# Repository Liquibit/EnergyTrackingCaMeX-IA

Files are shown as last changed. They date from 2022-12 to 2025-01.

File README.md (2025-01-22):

# EnergyTrackingCaMeX-IA
Energy tracking project for CaMéX-IA

This project exists of 4 parts:
- Energy Measurement device
- MODBUS-to-DASH7 device
- DASH7 gateway
- Gateway software to Scorpio

We will go over each part in this overview.

## Energy Measurement device

For this project, we used the Accuenergy AcuRev 1312-RCT-X0 together with 3 Rogowski coils. The official manual can be found [on their official website](https://www.accuenergy.com/wp-content/uploads/AcuRev-1312-User-Manual-Canada-Measurements-Approved.pdf). This device then measures the current over the three different phases and combines them. At the moment, only apparent and real energy are used in the rest of the project.

## MODBUS-to-DASH7 device

Custom hardware made by LiQuiBit. Every 10 minutes, it communicates over RS485 with the energy measurement device and sends this data over DASH7. 

The data gets structured as a file in the following format:

EnergyFile:
|Field|Type|
|---|---|
|apparent energy/phase 1|signed int 64|
|apparent energy/phase 2|signed int 64|
|apparent energy/phase 3|signed int 64|
|active energy/phase 1|signed int 64|
|active energy/phase 2|signed int 64|
|active energy/phase 3|signed int 64|
|Current/phase 1|signed int 32|
|Current/phase 2|signed int 32|
|Current/phase 3|signed int 32|
|Voltage/phase 1|signed int 16|
|Voltage/phase 2|signed int 16|
|Voltage/phase 3|signed int 16|
|Received Signal Strength|signed int 16|
|valid measurement|boolean|

Valid measurement indicates if it succeeded at reading out the values from the measurement device. 

You can find the firmware for this device in the DASH7-firmwares folder. 

For instructions on how to build or modify the application, you can take a look at [the LiQuiBit documentation](https://docs.liquibit.be/docs/Sub-iot/).

## DASH7 gateway

Using the [IOWAY gateway](https://www.liquibit.be/our_product.html) from LiQuiBit. Using the jumpers, the module is configured to forward DASH7 messages directly over UART instead of sending it to the ESP32. 

The firmware on the IOWAY gateway is the default IOWAY gateway application of the Sub-IoT stack. More information can be found in [the LiQuiBit documentation](https://docs.liquibit.be/docs/The-IOWAY-firmware/).

## Gateway software to Scorp-IO

For this project, this software was deployed on a raspberry pi. All necessary parts can be found in the Gateway-software folder.

The software is written in python3 as it's fully dependant on [the PyD7A library](https://github.com/liquibit/pyd7a). It is configured to receive messages from the serial connection, parse them into known files and forward it over MQTT to Scorp-IO. This sends all configuration to Scorp-IO on the first message of a device and does not require any extra configuration up front.

## Setting up the OS

First pull the code from the public github and put all aspects in the appropriate locations.
```
sudo git clone https://github.com/Liquibit/EnergyTrackingCaMeX-IA.git --recurse-submodules /opt/EnergyTrackingCaMeX-IA
sudo chmod +x /opt/EnergyTrackingCaMeX-IA/Gateway-software/os-config/gateway
sudo ln -s /opt/EnergyTrackingCaMeX-IA/Gateway-software/os-config/gateway /bin/gateway
sudo ln -s /opt/EnergyTrackingCaMeX-IA/Gateway-software/os-config/gateway.monit /etc/monit/conf.d/
sudo chown root:root /opt/EnergyTrackingCaMeX-IA/Gateway-software/os-config/PIOWAY
sudo ln -s /opt/EnergyTrackingCaMeX-IA/Gateway-software/os-config/PIOWAY /etc/logrotate.d/
```

This will set up the following things:
- Monit will make sure the code keeps running, restarts it when something goes wrong and starts it up on boot.
- Logrotate will rotate and compress the logs every week to make sure we're not using too much memory.

Then, make sure your python3 instance has all requirements installed
```
sudo python3 -m pip install -r /opt/EnergyTrackingCaMeX-IA/Gateway-software/pyd7a/requirements.txt
```

Now, you should be good to go after a reboot!

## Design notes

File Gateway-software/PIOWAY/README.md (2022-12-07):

# Gateway software for connection between DASH7 gateway and Siemens Mindsphere IoT Platform
This application sets up a connection with home assistant using MQTTS. The device should be configured up front using the UI or by posting to topics of the MQTT broker.

This application is meant to run on a raspberry Pi with a LiQuiBit IOWay gateway plugged into the USB port.

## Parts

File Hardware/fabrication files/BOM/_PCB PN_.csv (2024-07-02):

Comment | Description | Designator | Footprint | Quantity
SKSGACE010 | Keypad Switch, 1 Switches, SPST, Momentary-tactile, 0.05A, 12VDC, 1.6N, Solder Terminal, Surface Mount-straight | B1, B2 | RKC2SJF170SMTRLFS-Footprint-1 | 2
74LVC1G14GV | Inverter, LVC/LCX/Z Series, 1-Func, 1-Input, CMOS, PDSO5 | B3 | 74LVC1G14GV,125-Footprint-1 | 1
TDH541S485S | UART_MODBUS_CONVERTER | B4 | TD541S485H-Footprint-1 | 1
3RL090M-5-S | 3R-5-S Series 5 mm 600 V 5 kA Surface Mount Gas Discharge Tube | B5 | 2036-09-SM-RPLF-H-Footprint-1 | 1
CC0603KPX7R8BB105 | Ceramic Capacitor, Multilayer, Ceramic, 25V, 10% +Tol, 10% -Tol, X7R, 15% TC, 1uF, Surface Mount, 0603 | C1, C9, C19, C20 | FP-CC0603-DA-MFG | 4
C0603C103K2RACTU | Ceramic Capacitor, Multilayer, Ceramic, 200V, 10% +Tol, 10% -Tol, X7R, 15% TC, 0.01uF, Surface Mount, 0603 | C2 | FP-C0603C-CF-IPC_B | 1
GRM188Z71E225KE43D | Ceramic Capacitor, Multilayer, Ceramic, 25V, 10% +Tol, 10% -Tol, X7R, 15% TC, 2.2uF, Surface Mount, 0603 | C3 | FP-GRM188-0_2-IPC_C | 1
CC0603KRX7R9BB104 | Ceramic Capacitor, Multilayer, Ceramic, 25V, 10% +Tol, 10% -Tol, X7R, 15% TC, 0.1uF, Surface Mount, 0603 | C4, C8, C11, C13, C14, C16, C17, C18 | FP-0603-L_1_6_0_15-W_0_81-MFG | 8
GRM188R60J106ME47D | Ceramic Capacitor, Multilayer, Ceramic, 6.3V, 20% +Tol, 20% -Tol, X5R, 15% TC, 10uF, Surface Mount, 0603 | C10, C12 | FP-GRM188-0_1-e0_2_0_55-MFG | 2
CC1206KKX7RDBB102 | Ceramic Capacitor, Multilayer, Ceramic, 2000V, 10% +Tol, 10% -Tol, X7R, 15% TC, 0.001uF, Surface Mount, 1206 | C15 | FP-CC1206-0_3-1_45-IPC_A | 1
CC0603KRX7R9BB101 | Ceramic Capacitor, Multilayer, Ceramic, 50V, 10% +Tol, 10% -Tol, X7R, 15% TC, 0.0001uF, Surface Mount, 0603 | C21, C22 | FP-CC0603-DA-IPC_B | 2
APT1608SURCK | Single Color LED, Hyper Red, Water Clear, 1.2mm | D1, D4 | FP-APT1608EC-MFG | 2
SMAJ5.0A | Trans Voltage Suppressor Diode, 400W, 5V V(RWM), Unidirectional, 1 Element, Silicon, DO-214AC | D2 | BOUR-SMA-2_V | 1
APG1608CGKC/T | Single Color LED, Green, Water Clear, 1.2mm | D3 | FP-APG1608CGKC-T-MFG | 1
2920L075DR | PTC Thermistor, 30V, 0.35ohm, Surface Mount | F1 | FP-2920L050DR-MFG | 1
BLM18AG121SN1D | Chip Ferrite Bead, 0603, 120O @ 100MHz, 0.18O, 25%, 800mA | FB1 | FP-BLM18-0_15-t0_8-IPC_B | 1
VI0921550000G | Barrier Strip Terminal Block | j4 | VI0921550000G-Footprint-1 | 1
HJ-SMA402 | RF SMA Connector | J5 | CON-REVSMA-RA | 1
105133-0001 | USB Connector, 5 Contact(s), Female, Right Angle, Surface Mount Terminal, Locking, Receptacle | J6 | MOLX-105133-0001_V | 1
ACM2520-301-2P-T002 | Ferrite Chip, 2 Function(s), 20V, 0.4A, 4 Pin(s) | L1 | FP-ACM2520-2P-MFG | 1
CMWX1ZZABZ-078 | Microcontroller/radio package | MD1 | FP-CMWX1ZZABZ-078-MFG | 1
PZ127VS-12-10-H10-A38 | Male Header, Pitch 1.27 mm, 2 x 5 Position, Height 5.96 mm, -55 to 125 degC, RoHS, Bulk | P1 | SMTC-FTSH-105-01-L-DV_V | 1
RL1210FR-070R5L | Fixed Resistor, Metal Glaze/thick Film, 0.5W, 0.5ohm, 0.5V, 1% +/-Tol, 300ppm/Cel, Surface Mount, 1210 | R1 | RESC3126X65X50NL10T20 | 1
AC0805FR-07100RL | Fixed Resistor, Metal Glaze/thick Film, 0.125W, 100ohm, 150V, 1% +/-Tol, 100ppm/Cel, Surface Mount, 0805 | R2, R3, R4 | FP-AC0805-IPC_A | 3
CRCW04020000Z0ED | Metal Glaze/thick Film, 0.063W, 0ohm, Surface Mount, 0402 | R7, R12, R14 | FP-CRCW0402-e3-IPC_A | 7
RC0402FR-0710KL | Fixed Resistor, Metal Glaze/thick Film, 0.0625W, 10000ohm, 50V, 1% +/-Tol, 100ppm/Cel, Surface Mount, 0402 | R8 | RESC1005X40X25NL05T10 | 1
RT1206FRE071ML | Fixed Resistor, Thin Film, 0.25W, 1000000ohm, 200V, 1% +/-Tol, 50ppm/Cel, Surface Mount, 1206 | R9 | RESC3116X65X40ML10T20 | 1
CRCW12061K00JNEC | Fixed Resistor, Metal Glaze/thick Film, 0.25W, 1000ohm, 200V, 5% +/-Tol, 200ppm/Cel, Surface Mount, 1206 | R10, R18 | FP-CRCW1206-e3-IPC_A | 2
SMW22R7JT | Fixed Resistor, Wire Wound, 2W, 2.7ohm, 300V, 5% +/-Tol, 200ppm/Cel, Surface Mount, 2616 | R11, R15 | SMW22R7JT-Footprint-1 | 2
PTS526SK15SMTR2LFS | TACT 5.2 X 5.2, 1.5 MM H, 260GF, | SW1 | FP-PTS526SK15SMTR2LFS-MFG | 1
SPX3819M5-L-3-3/TR | Fixed Positive LDO Regulator, 3.3V, 0.7V Dropout, PDSO5 | U1 | SOT95P280X145-5N | 1
TPD2S017DBVR | Trans Voltage Suppressor Diode, 5V V(RWM), Unidirectional, 4 Element, Silicon | U2 | DBV0006A_N | 1
SM712.TCT | Trans Voltage Suppressor Diode, 400W, 12V V(RWM), Unidirectional, 4 Element, Silicon | U3 | SMTC-SOT23-3_V | 1

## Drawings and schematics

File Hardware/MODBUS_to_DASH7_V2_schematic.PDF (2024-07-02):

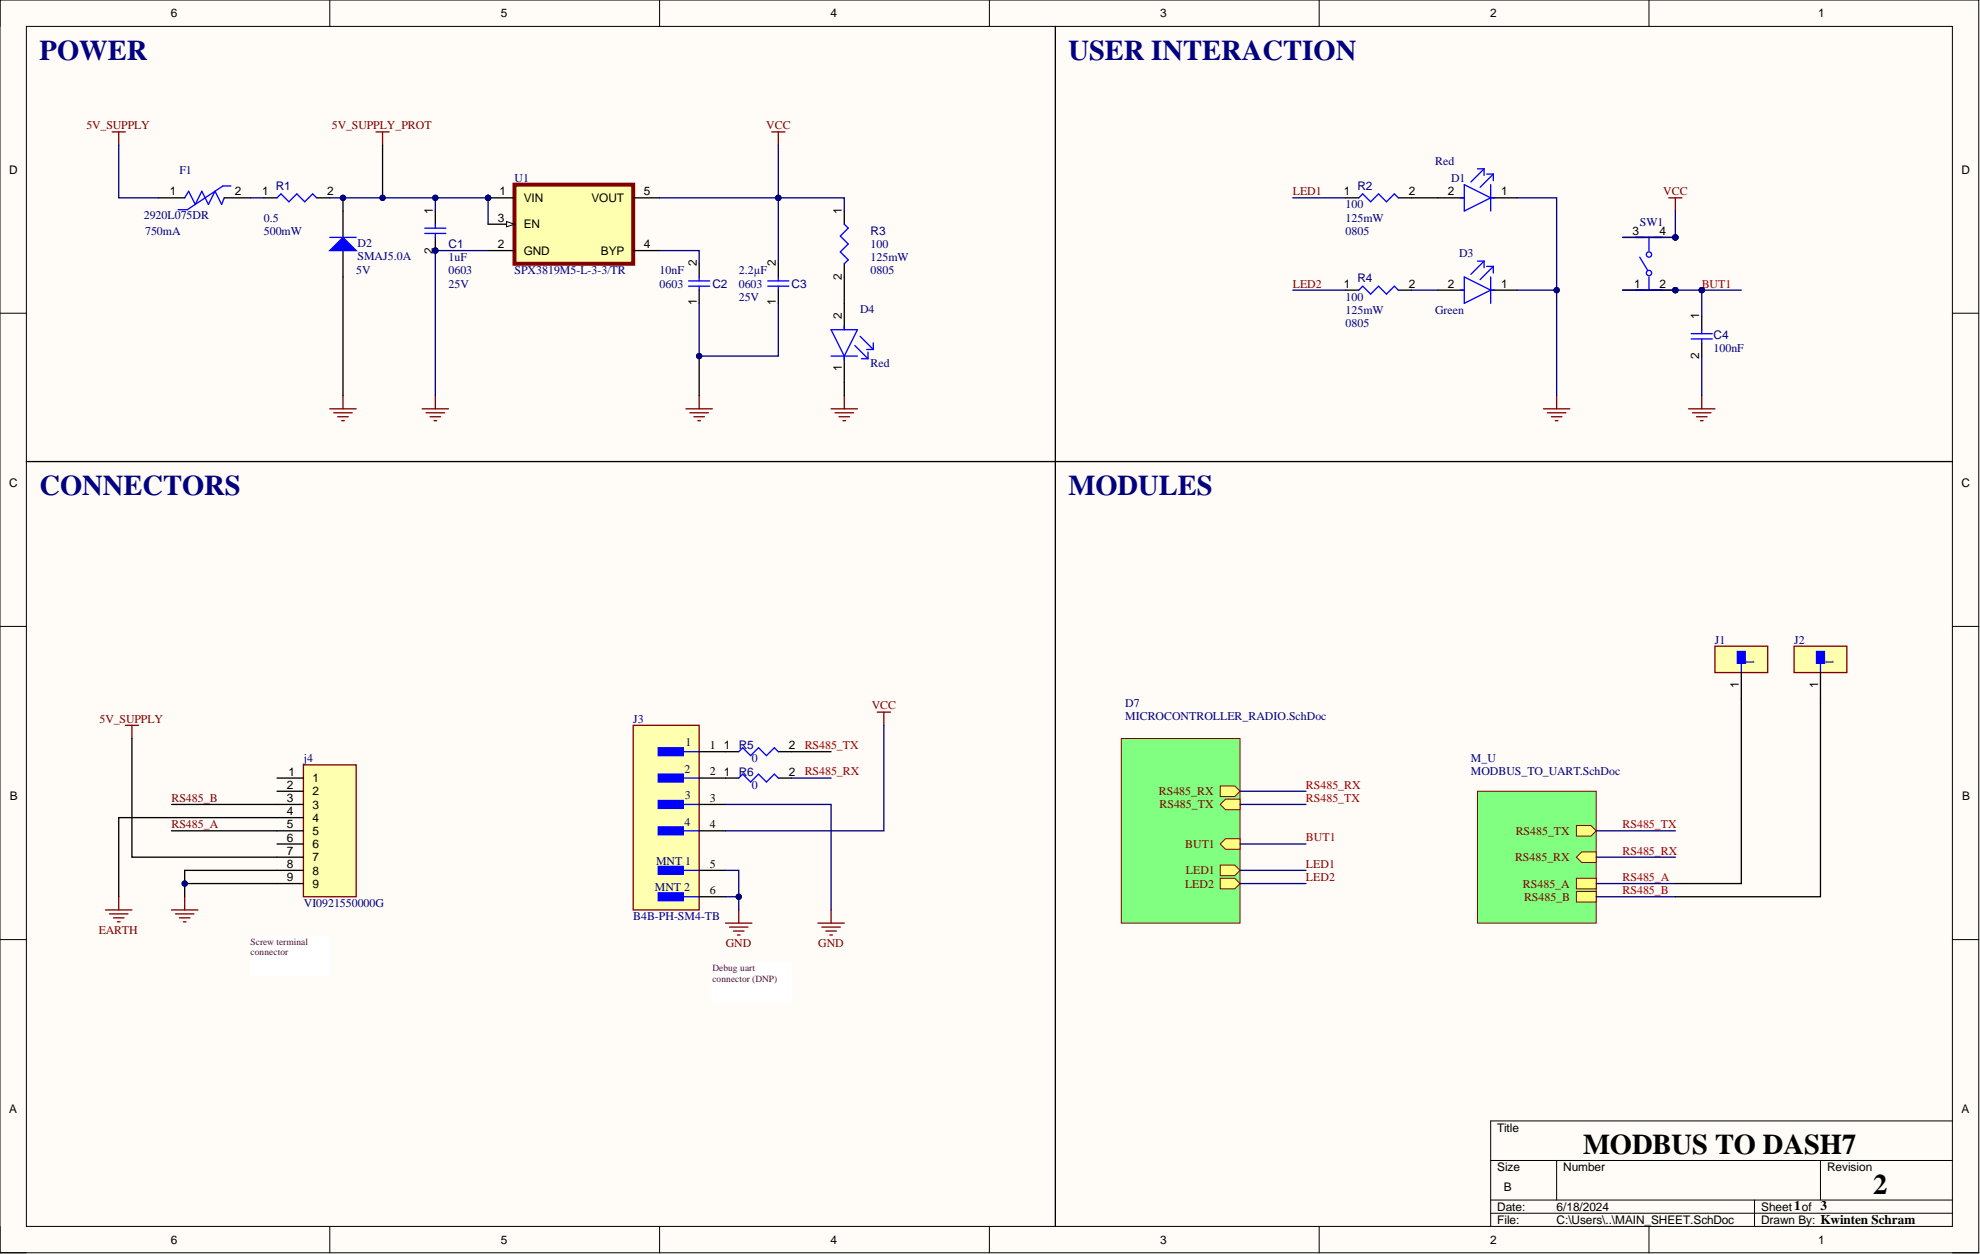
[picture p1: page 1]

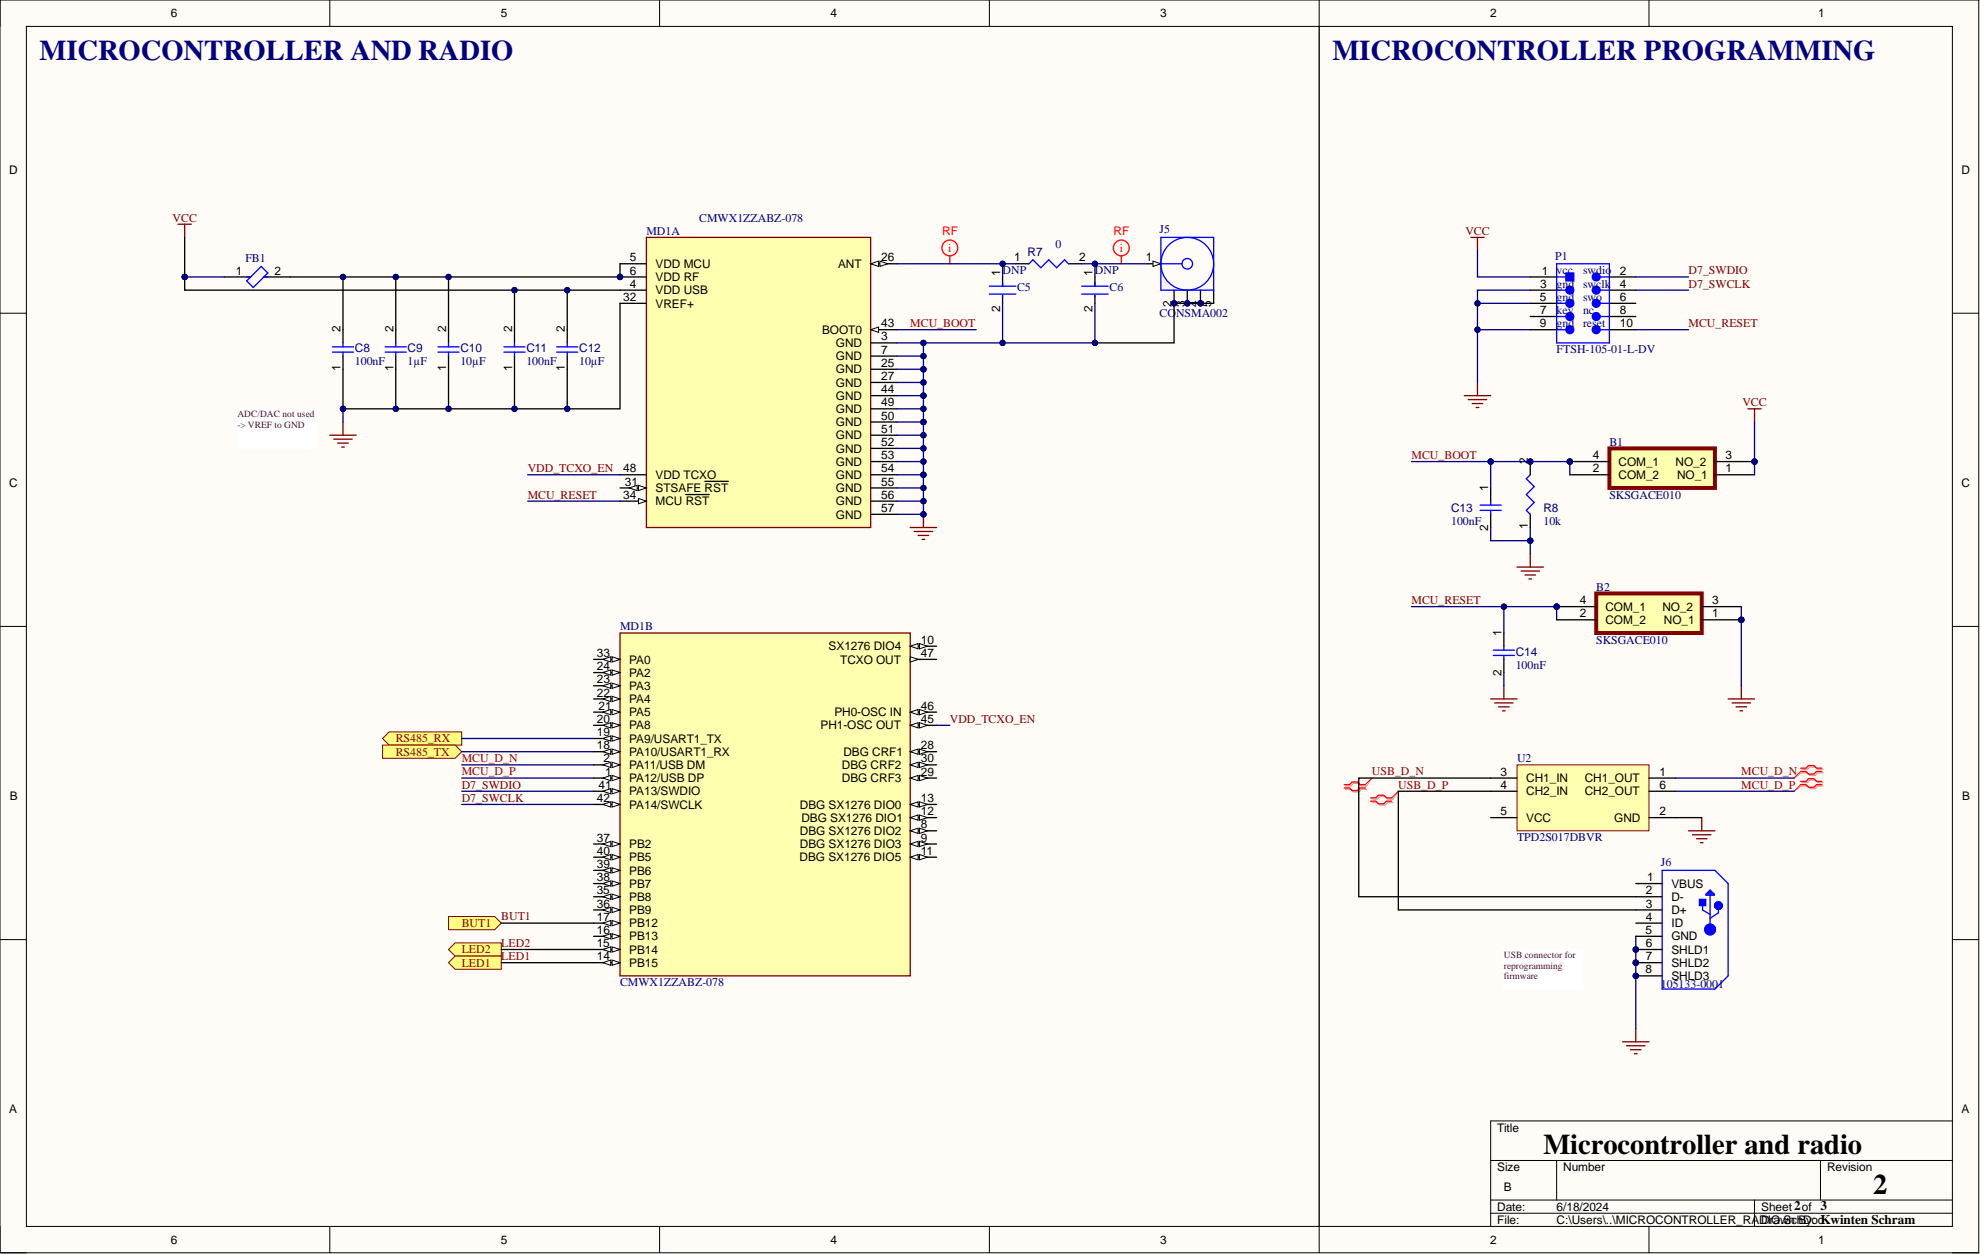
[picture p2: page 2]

ADC/DAC not used
-> VREF to GND

USB_D_P | CH2_IN 4

VCC 5

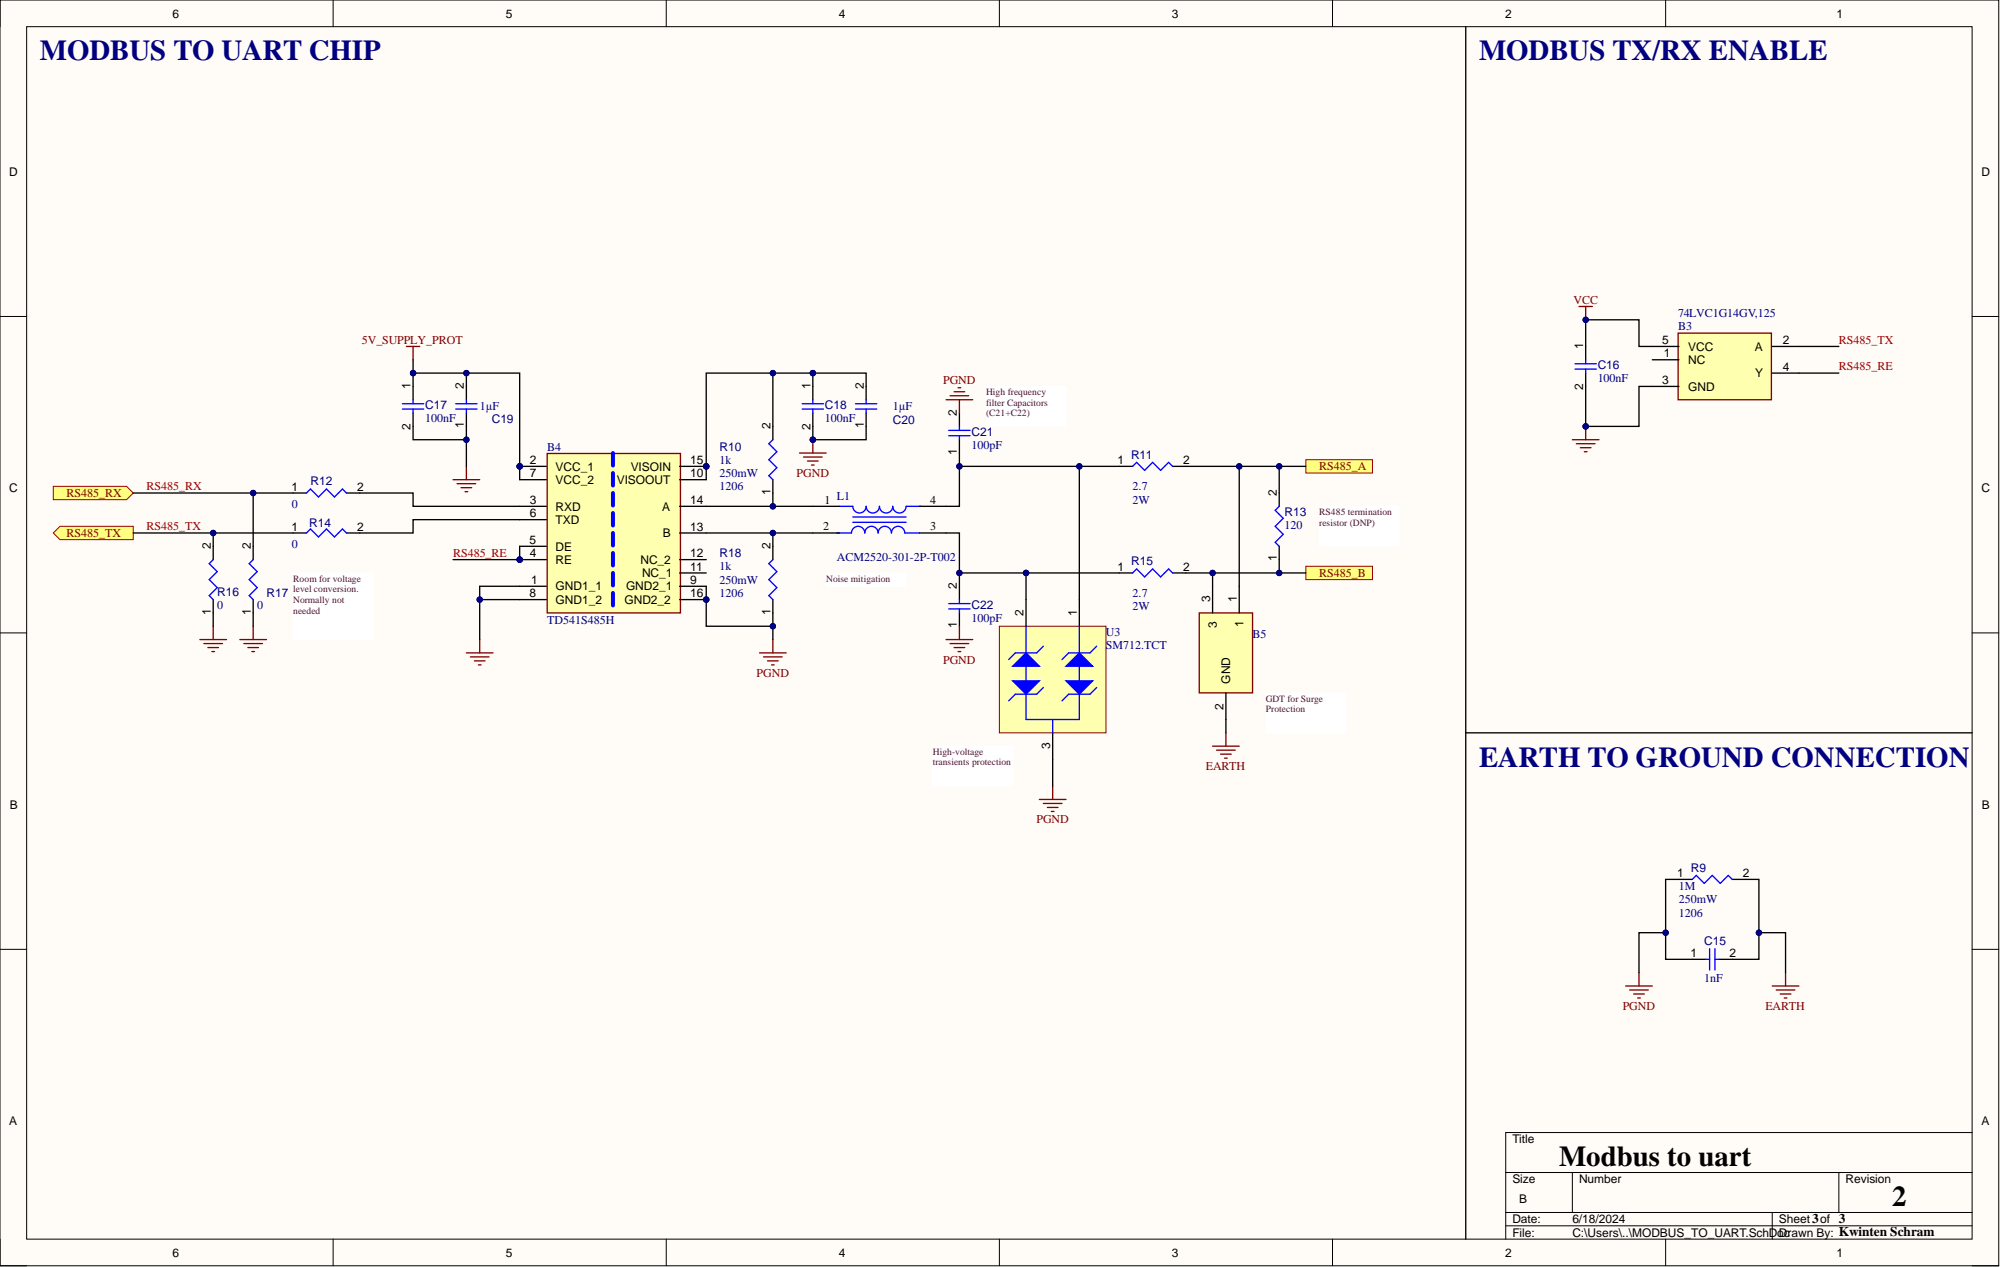
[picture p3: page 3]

MODBUS TX/RX ENABLE

MODBUS TO UART CHIP

EARTH TO GROUND CONNECTION

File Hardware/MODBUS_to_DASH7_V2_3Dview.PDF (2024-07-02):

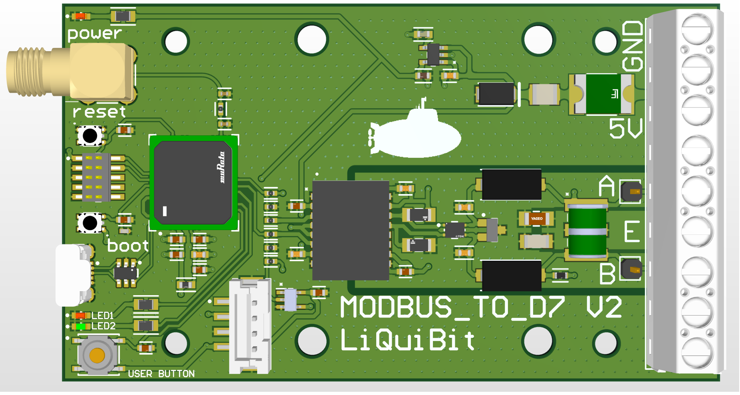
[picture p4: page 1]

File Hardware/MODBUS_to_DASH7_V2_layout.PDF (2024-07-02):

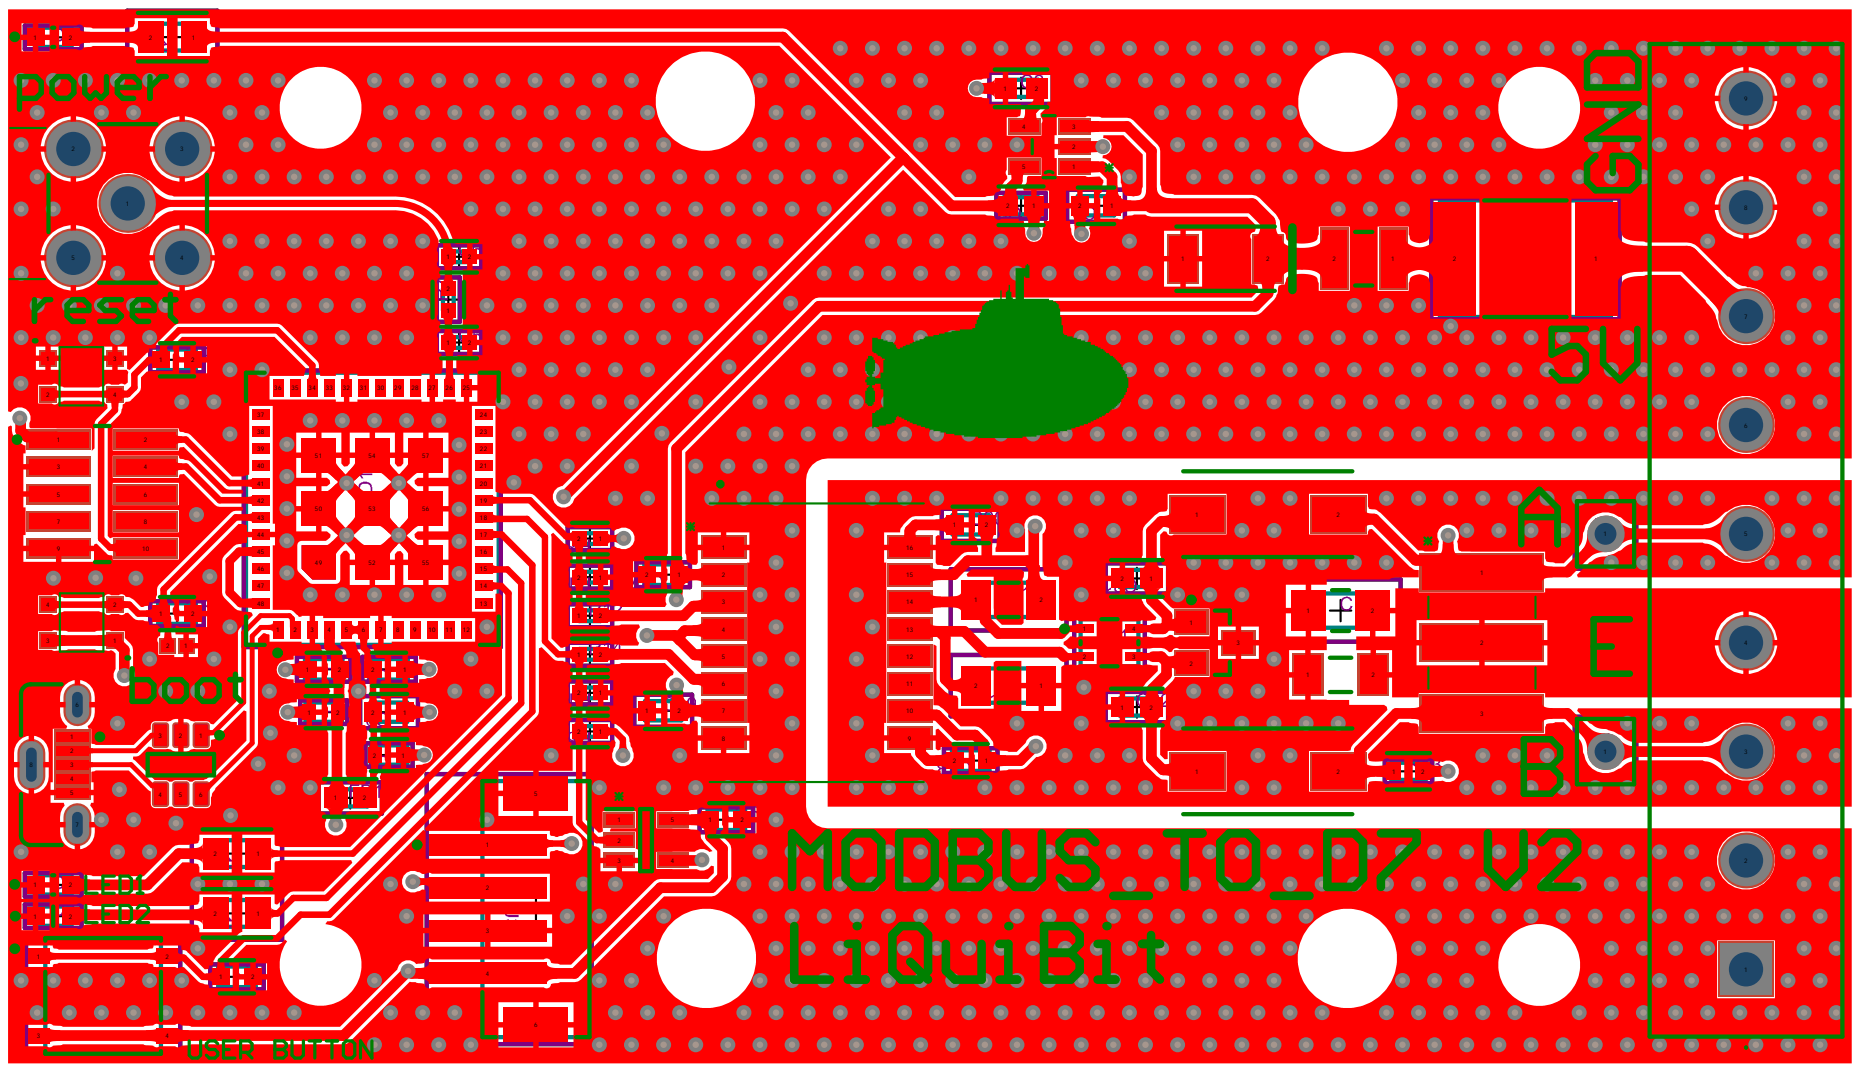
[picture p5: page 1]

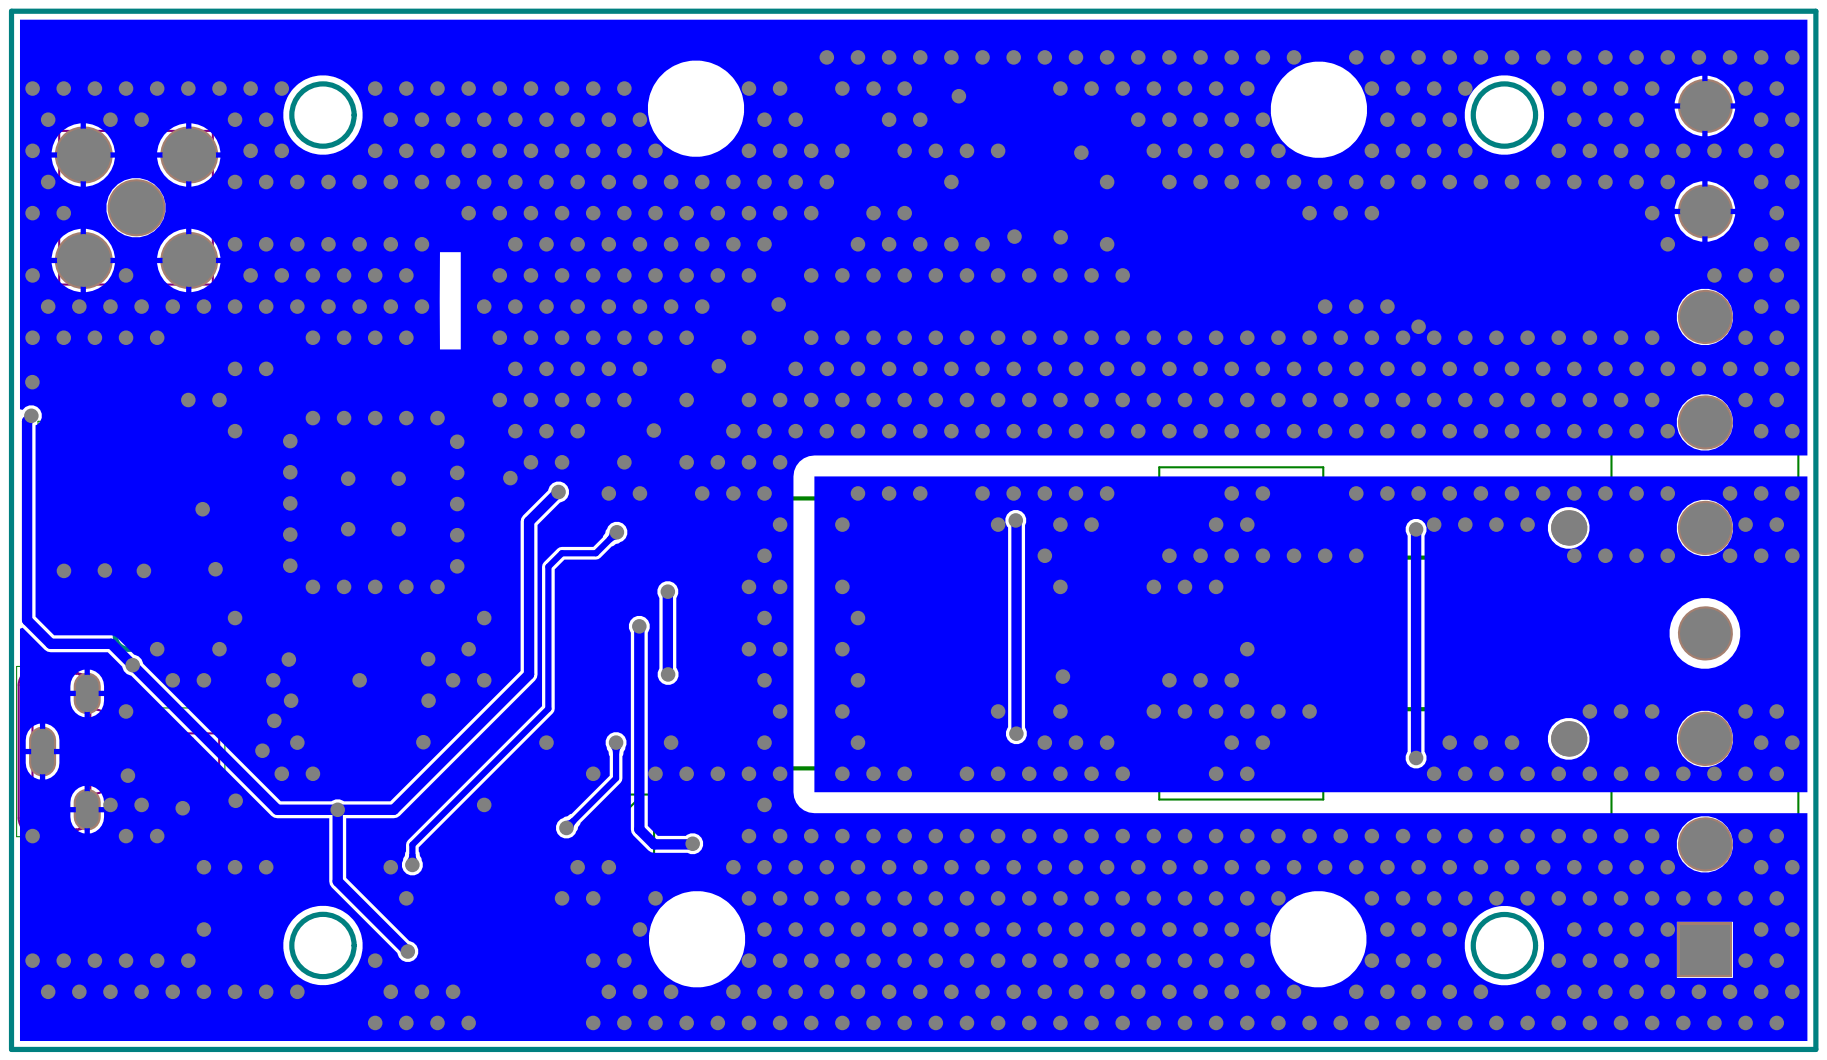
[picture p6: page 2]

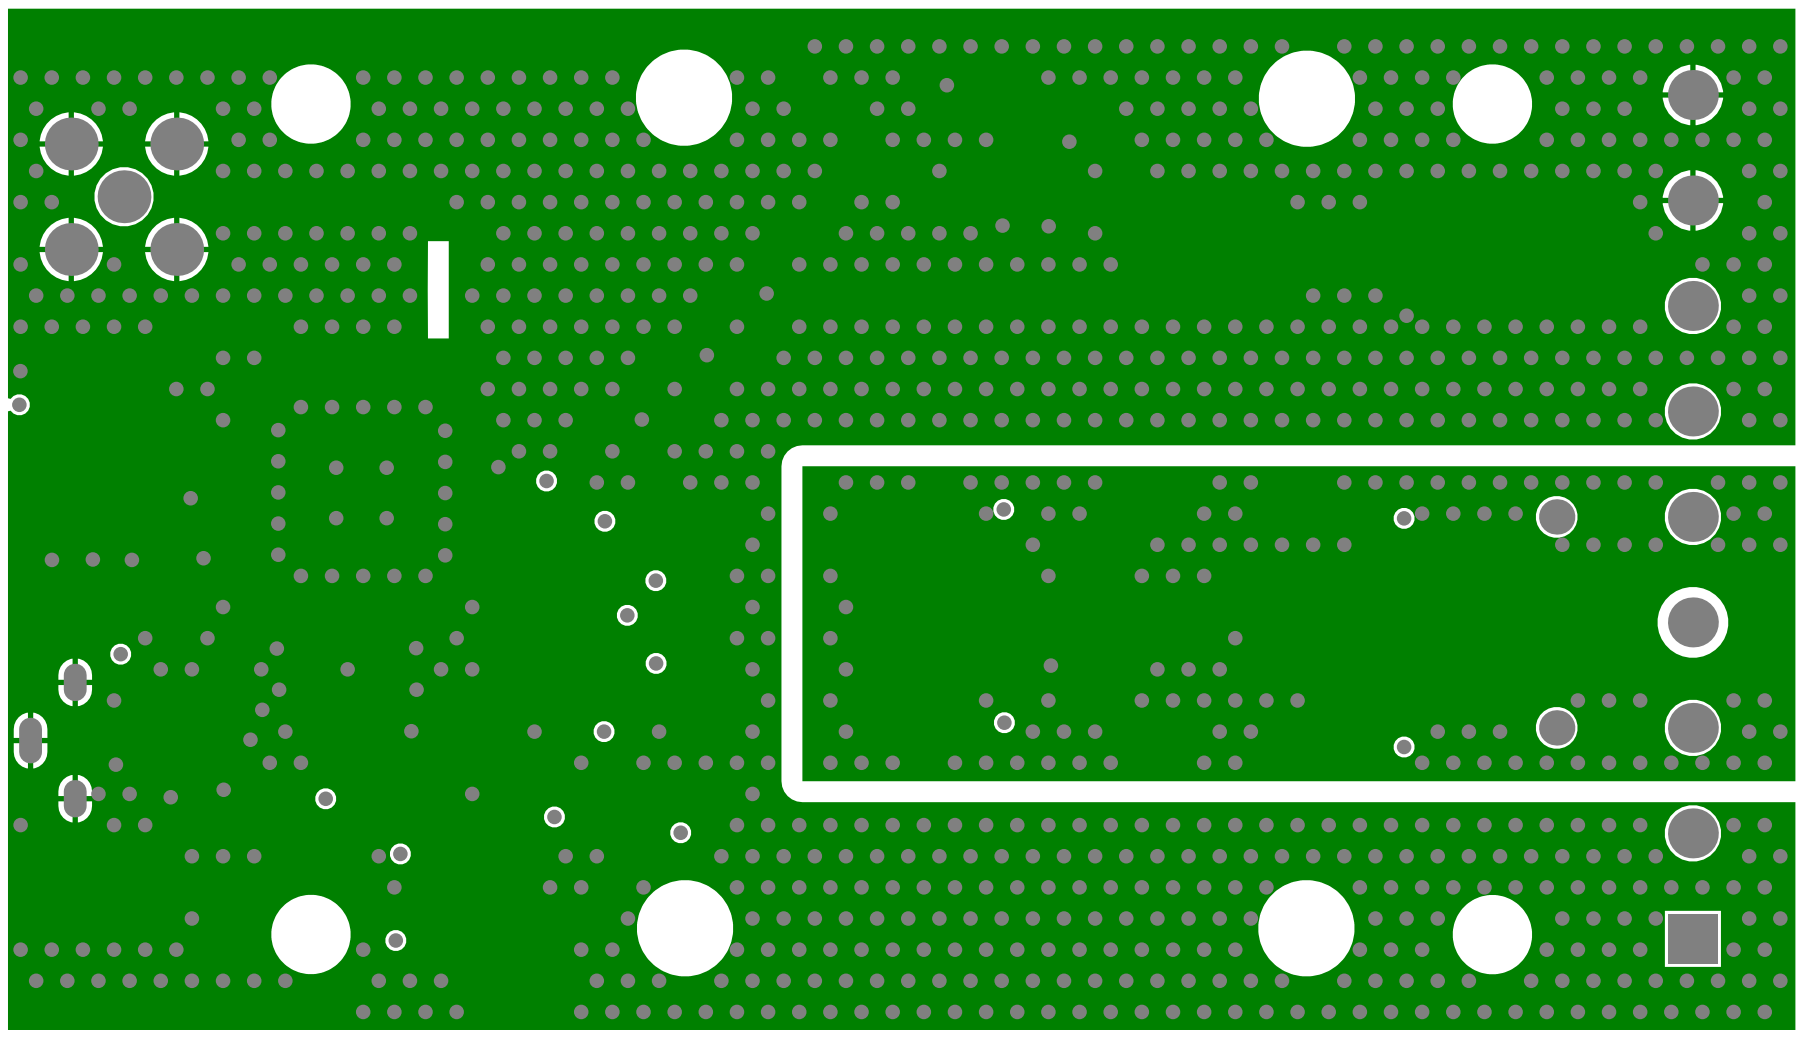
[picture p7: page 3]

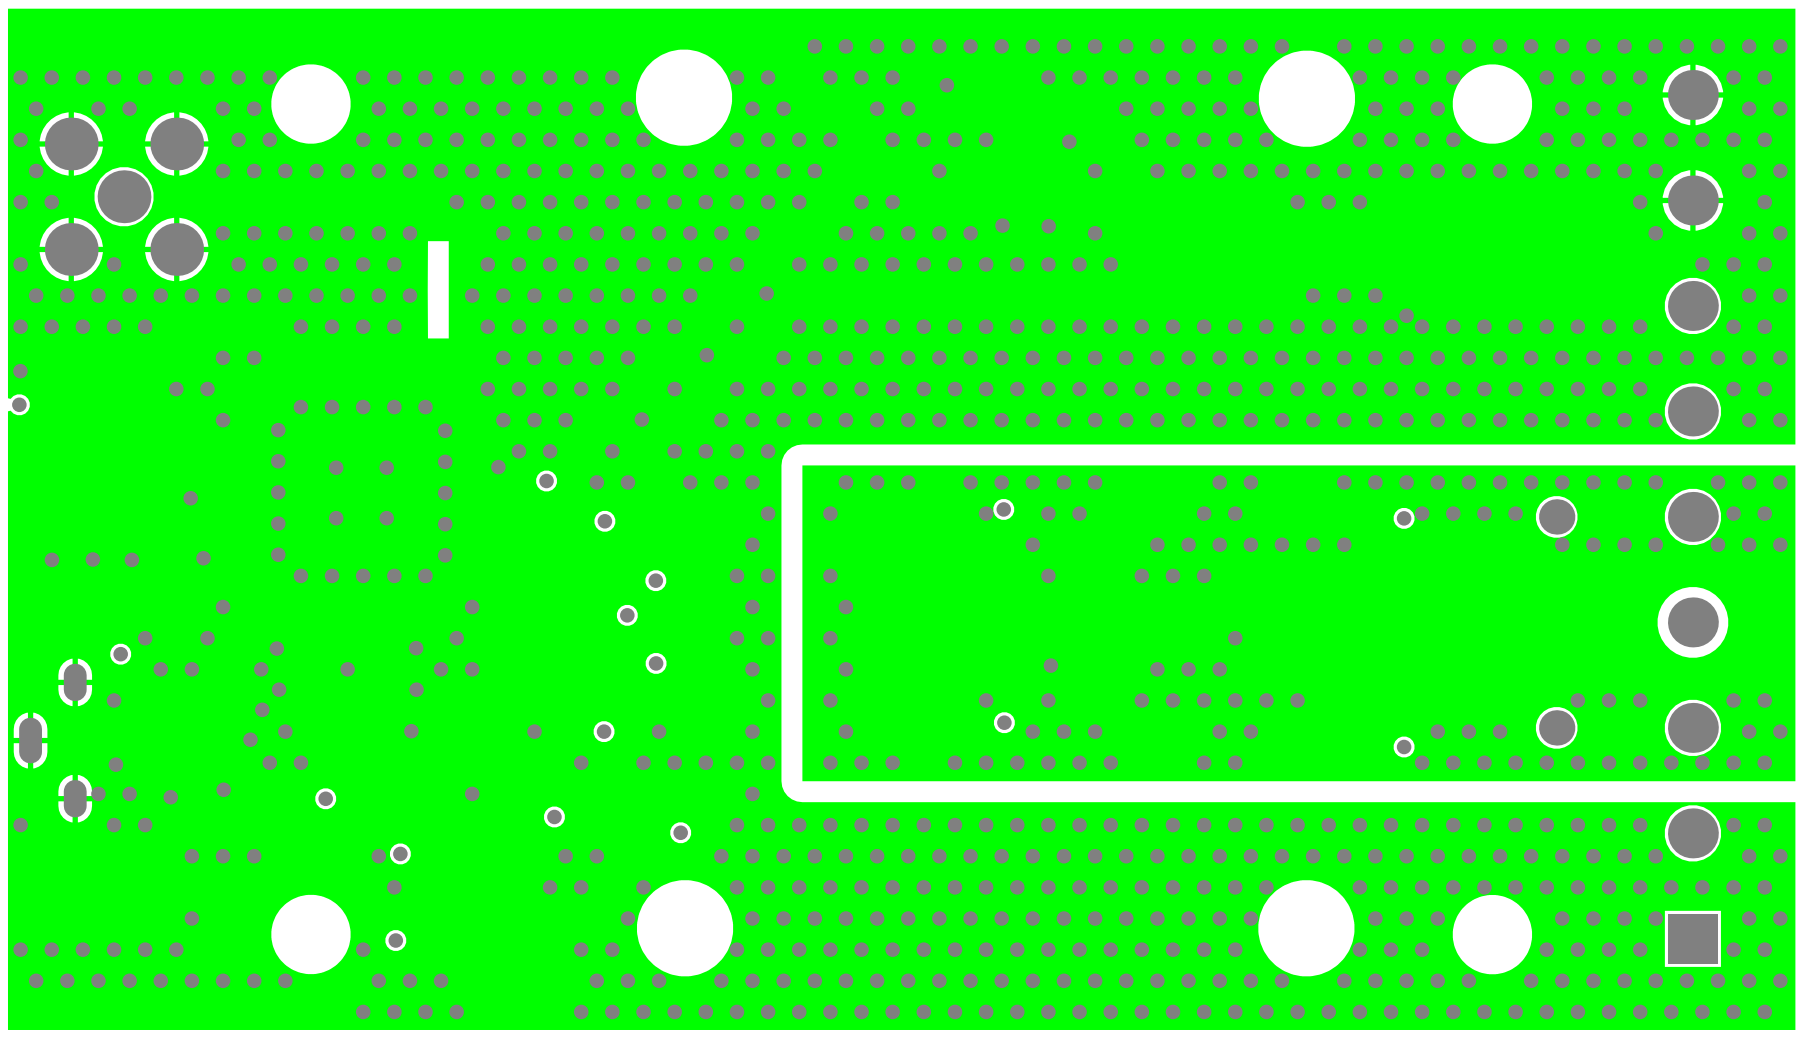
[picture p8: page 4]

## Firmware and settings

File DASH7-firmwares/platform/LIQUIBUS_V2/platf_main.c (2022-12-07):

/*
 * Copyright (c) 2015-2021 University of Antwerp, Aloxy NV, LiQuiBit VOF.
 *
 * This file is part of Sub-IoT.
 * See https://github.com/Sub-IoT/Sub-IoT-Stack for further info.
 *
 * Licensed under the Apache License, Version 2.0 (the "License");
 * you may not use this file except in compliance with the License.
 * You may obtain a copy of the License at
 *
 *     http://www.apache.org/licenses/LICENSE-2.0
 *
 * Unless required by applicable law or agreed to in writing, software
 * distributed under the License is distributed on an "AS IS" BASIS,
 * WITHOUT WARRANTIES OR CONDITIONS OF ANY KIND, either express or implied.
 * See the License for the specific language governing permissions and
 * limitations under the License.
 */

/* \file
 *
 *
 * @author contact@liquibit.be
 */

#include "bootstrap.h"
#include "button.h"
#include "debug.h"
#include "errors.h"
#include "hwdebug.h"
#include "hwgpio.h"
#include "hwi2c.h"
#include "hwleds.h"
#include "hwradio.h"
#include "hwsystem.h"
#include "led.h"
#include "stm32_common_gpio.h"
#include "stm32_device.h"

#define I2C_BAUDRATE 400000

// defined in linker script
extern uint32_t __d7ap_fs_metadata_start;
extern uint32_t __d7ap_fs_metadata_end;
extern uint32_t __d7ap_fs_permanent_files_start;
extern uint32_t __d7ap_fs_permanent_files_end;

static blockdevice_stm32_eeprom_t metadata_bd;
static blockdevice_stm32_eeprom_t permanent_files_bd;

extern uint8_t d7ap_volatile_files_data[FRAMEWORK_FS_VOLATILE_STORAGE_SIZE];
static blockdevice_ram_t ram_bd = (blockdevice_ram_t) { .base.driver = &blockdevice_driver_ram,
    .base.size = FRAMEWORK_FS_VOLATILE_STORAGE_SIZE,
    .buffer = d7ap_volatile_files_data };

blockdevice_t* const metadata_blockdevice = (blockdevice_t* const)&metadata_bd;
blockdevice_t* const persistent_files_blockdevice = (blockdevice_t* const)&permanent_files_bd;
blockdevice_t* const volatile_blockdevice = (blockdevice_t* const)&ram_bd;
static i2c_handle_t* i2c;

static GPIO_InitTypeDef output_config
    = { .Mode = GPIO_MODE_OUTPUT_PP, .Pull = GPIO_NOPULL, .Speed = GPIO_SPEED_FREQ_HIGH };


void hw_radio_reset()
{
    error_t e;
    e = hw_gpio_configure_pin(SX127x_RESET_PIN, false, GPIO_MODE_OUTPUT_PP, 0);
    assert(e == SUCCESS);
    hw_busy_wait(150);
    e = hw_gpio_configure_pin(SX127x_RESET_PIN, false, GPIO_MODE_INPUT, 1);
    assert(e == SUCCESS);
    hw_busy_wait(10000);
}

void __platform_init()
{
    __gpio_init();

    // init blockdevices
    // the embedded EEPROM is divided in 2 logical block devices, 1 for metadata and 1 for permanent files
    blockdevice_stm32_eeprom_t* stm32_eeprom_metadata_bd = (blockdevice_stm32_eeprom_t*)metadata_blockdevice;
    stm32_eeprom_metadata_bd->base.driver = &blockdevice_driver_stm32_eeprom;
    stm32_eeprom_metadata_bd->base.offset = 0;
    stm32_eeprom_metadata_bd->base.size
        = (uint32_t)((uint8_t*)&__d7ap_fs_metadata_end - (uint8_t*)&__d7ap_fs_metadata_start);

    blockdevice_init(metadata_blockdevice);

    blockdevice_stm32_eeprom_t* stm32_eeprom_permanent_files_bd
        = (blockdevice_stm32_eeprom_t*)persistent_files_blockdevice;
    stm32_eeprom_permanent_files_bd->base.driver = &blockdevice_driver_stm32_eeprom;
    stm32_eeprom_permanent_files_bd->base.offset = (uint32_t)((uint8_t*)&__d7ap_fs_metadata_end
        - (uint8_t*)&__d7ap_fs_metadata_start); // blockdevices begins after metadata block device // TODO aligment on
                                                // sector?
    stm32_eeprom_permanent_files_bd->base.size
        = (uint32_t)((uint8_t*)&__d7ap_fs_permanent_files_end - (uint8_t*)&__d7ap_fs_permanent_files_start);

    blockdevice_init(persistent_files_blockdevice);
    blockdevice_init(volatile_blockdevice);

    hw_radio_io_init(true);
    hw_radio_reset();
}

void __platform_post_framework_init()
{
    __ubutton_init();
    led_init();
}

int main()
{
    // initialise the platform itself
    __platform_init();
    // do not initialise the scheduler, this is done by __framework_bootstrap()
    __framework_bootstrap();
    // initialise platform functionality that depends on the framework
    __platform_post_framework_init();

    scheduler_run();
    return 0;
}

// override the weak definition
void hw_radio_io_init(bool disable_interrupts)
{
    // configure the radio GPIO pins here, since hw_gpio_configure_pin() is MCU
    // specific and not part of the common HAL API
    hw_gpio_configure_pin(SX127x_DIO0_PIN, true, GPIO_MODE_INPUT, 0);
    hw_gpio_configure_pin(SX127x_DIO1_PIN, true, GPIO_MODE_INPUT, 0);

    if (disable_interrupts) {
        hw_gpio_disable_interrupt(SX127x_DIO1_PIN);
        hw_gpio_disable_interrupt(SX127x_DIO0_PIN);
    }

    // Antenna switching uses 3 pins on murata ABZ module
    hw_gpio_configure_pin(ABZ_ANT_SW_RX_PIN, false, GPIO_MODE_OUTPUT_PP, 0);
    hw_gpio_configure_pin(ABZ_ANT_SW_TX_PIN, false, GPIO_MODE_OUTPUT_PP, 0);
    hw_gpio_configure_pin(ABZ_ANT_SW_PA_BOOST_PIN, false, GPIO_MODE_OUTPUT_PP, 0);

#ifdef PLATFORM_SX127X_USE_DIO3_PIN
    hw_gpio_configure_pin(SX127x_DIO3_PIN, true, GPIO_MODE_INPUT, 0);
    if (disable_interrupts)
        hw_gpio_disable_interrupt(SX127x_DIO3_PIN);
#endif
    hw_gpio_configure_pin(SX127x_VCC_TXCO, false, GPIO_MODE_OUTPUT_PP, 1);
    hw_gpio_set(SX127x_VCC_TXCO);
}

// override the weak definition
void hw_radio_io_deinit()
{
    GPIO_InitTypeDef initStruct = { 0 };
    initStruct.Mode = GPIO_MODE_ANALOG;

    hw_gpio_configure_pin_stm(SX127x_DIO0_PIN, &initStruct);
    hw_gpio_configure_pin_stm(SX127x_DIO1_PIN, &initStruct);
#ifdef PLATFORM_SX127X_USE_DIO3_PIN
    hw_gpio_configure_pin_stm(SX127x_DIO3_PIN, &initStruct);
#endif
    hw_gpio_configure_pin_stm(ABZ_ANT_SW_RX_PIN, &initStruct);
    hw_gpio_clr(ABZ_ANT_SW_RX_PIN);
    hw_gpio_configure_pin_stm(ABZ_ANT_SW_TX_PIN, &initStruct);
    hw_gpio_clr(ABZ_ANT_SW_TX_PIN);
    hw_gpio_configure_pin_stm(ABZ_ANT_SW_PA_BOOST_PIN, &initStruct);
    hw_gpio_clr(ABZ_ANT_SW_PA_BOOST_PIN);
#ifdef PLATFORM_SX127X_USE_RESET_PIN
    hw_gpio_configure_pin_stm(SX127x_RESET_PIN, &initStruct);
#endif
    hw_gpio_configure_pin_stm(SX127x_VCC_TXCO, &initStruct);
}

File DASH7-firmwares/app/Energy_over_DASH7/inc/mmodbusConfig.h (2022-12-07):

#ifndef _MMODBUS_CONFIG_H_
#define _MMODBUS_CONFIG_H_

#define _MMODBUS_FREERTOS         0
#define _MMODBUS_RTU              1
#define _MMODBUS_ASCII            0 //  not implemented yet
#define _MMODBUS_USART            USART1             
#define _MMODBUS_RXSIZE           64  
#define _MMODBUS_TXDMA            0
#if     _MMODBUS_TXDMA == 1
#define _MMODBUS_DMA              DMA2
#define _MMODBUS_DMASTREAM        LL_DMA_STREAM_7   
#endif
// #define _MMODBUS_CTRL_GPIO        RS485_CTRL_GPIO_Port
// #define _MMODBUS_CTRL_PIN         RS485_CTRL_Pin


#if (_MMODBUS_RTU == 1) && (_MMODBUS_ASCII == 1)
#error please select _MMODBUS_RTU or _MMODBUS_ASCII
#endif
#endif

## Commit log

2024-05-18 add handling for button press and ensure other files don't send empty data
2024-05-18 bugfix device ID and button press, button file also tested
2024-05-19 change current to 4 bytes
2024-06-05 optimize modbus read, add energy reset functions
    [AcuRev_1312_RCT.c, mmodbus.c, mmodbus.h]
2024-06-15 reset energy on button pressed boot
    [AcuRev_1312_RCT.c]
2024-06-18 hardware files
    [MAIN_SHEET.SchDoc, MICROCONTROLLER_RADIO.SchDoc, MODBUS_TO_UART.SchDoc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]
